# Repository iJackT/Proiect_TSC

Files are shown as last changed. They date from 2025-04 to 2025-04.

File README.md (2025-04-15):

OpenBook E-book Reader

Urmatorul fisier contine detalii despre implmentarea proiectului

Descriere generala
OpenBook este un e-reader open-source construit pe baza unui controller ESP32-C6. Acesta se foloseste de un ecran de 7.5" dar nu numai.

Diagrama Bloc:



Componente importante:

Microcontroller – ESP32-C6-WROOM-1
CPU: RISC-V pe 32 de biți, frecvență de 160 MHz
Memorie: 512 KB SRAM + 8 MB flash extern (model W25Q512JVEIQ)
Conectivitate: Suportă Wi-Fi 6 (802.11ax), Bluetooth 5 Low Energy, USB 2.0 Full-Speed

Ecran E-Ink – Waveshare WSH-13187, 7.5”
Rezoluție afișaj: 800x480 pixeli, alb-negru
Comunicare: Interfață SPI cu fire dedicate CS, DC, RST, BUSY
Consum de curent: Între 15–25 mA la reîmprospătare, consum nul în stare statică

Senzor ambiental – Bosch BME688
Măsurători: Temperatură, umiditate, presiune, calitate aer (eCO2, TVOC)
Precizie: ±1 °C (temperatură), ±3% (umiditate), ±1 hPa (presiune)
Comunicare: Protocol I²C @ 400 kHz

Alimentare și gestiunea energiei
Baterie: Li-Po 3.7V, capacitate 2500 mAh
Monitorizare baterie: MAX17048 (interfață I²C)
Încărcare: MCP73831, input 5V/1A prin conector USB-C

Interfață butoane – 3x switch tactil
Tip: Panasonic EVQ-Q2A03W
Legătură: GPIO cu debounce hardware (filtru RC)
Utilizare: Navigare în meniu, derulare pagini, confirmare acțiuni

Conector USB-C
Funcții: Încărcare baterie și transfer de date prin USB 2.0
Protecții: ESD și rezistențe de terminare corect configurate
Capabilități adiționale: Suport actualizări firmware prin USB și OTA prin Wi-Fi

Conector rapid I²C – Qwiic / STEMMA QT
Pini: VCC, GND, SDA, SCL
Rol: Permite conectarea ușoară a modulelor și senzorilor compatibili I²C

Slot MicroSD – Attend 112A-TAAR-R03
Scop: Permite stocarea externă de fișiere (cărți, jurnale, firmware)
Interfață: Conectare prin SPI

Ceas de timp real (RTC) – DS3231
Precizie: ±2 ppm
Interfață: I²C
Backup: Alimentare de rezervă prin supercapacitor

Pini folositi

| Pin ESP32-C6 | Componentă / Semnal | De ce? |
|---|---|---|
| GPIO1 | I²C SDA (BME688, MAX17048, DS3231, Qwiic) | Linie partajată I²C – economisește pini și permite extinderea facilă |
| GPIO2 | I²C SCL (BME688, MAX17048, DS3231, Qwiic) | Clock I²C pentru toți senzorii și extensii Qwiic |
| GPIO5 | SPI MISO (E-Paper, Flash extern) | Linie comună de intrare date în SPI |
| GPIO6 | SPI MOSI (E-Paper, Flash extern) | Linie de ieșire date către e-paper și flash |
| GPIO7 | SPI CLK | Semnal de clock pentru magistrala SPI |
| GPIO8 | E-Paper CS | Selectează afișajul pe magistrala SPI |
| GPIO9 | E-Paper DC (Data/Command) | Comută între comandă și date către e-paper |
| GPIO10 | E-Paper RST | Reset hardware e-paper |
| GPIO11 | E-Paper BUSY | Pin de stare (ocupat/liber) de la display |
| GPIO12 | Button #1 | Intrare digitală pentru navigare pagină înainte |
| GPIO13 | Button #2 | Intrare digitală pentru navigare pagină înapoi |
| GPIO14 | Button #3 | Intrare digitală pentru selectare/opțiune |
| GPIO15 | MAX17048 ALERT (opțional) | Pin de alertă nivel scăzut baterie |
| GPIO16 | USB D+ (intern la USB PHY) | Linie USB 2.0 (fixă pe ESP32-C6) |
| GPIO17 | USB D- (intern la USB PHY) | Linie USB 2.0 (fixă pe ESP32-C6) |
| GPIO18 | LED Status (opțional) | Indicator pentru activitate Wi-Fi, charging, notificări |
| GPIO19 | SD Card CS | Selectare chip pentru card microSD (SPI) |
| GPIO20 | SD Card MISO | Citire date de pe card microSD |
| GPIO21 | SD Card MOSI | Scriere date pe card microSD |
| GPIO4 | SD Card CLK | Semnal de clock pentru card microSD (SPI) |

Comunicatii si Interfete

| Tip | Componente |
|---|---|
| **SPI** | E-Paper, Flash extern, SD Card (în mod SPI) |
| **I²C** | BME688, MAX17048, DS3231, Qwiic/Stemma |
| **USB** | Încărcare și transfer date prin USB-C |
| **GPIO**  | Butoane, semnale control afișaj, charging enable |

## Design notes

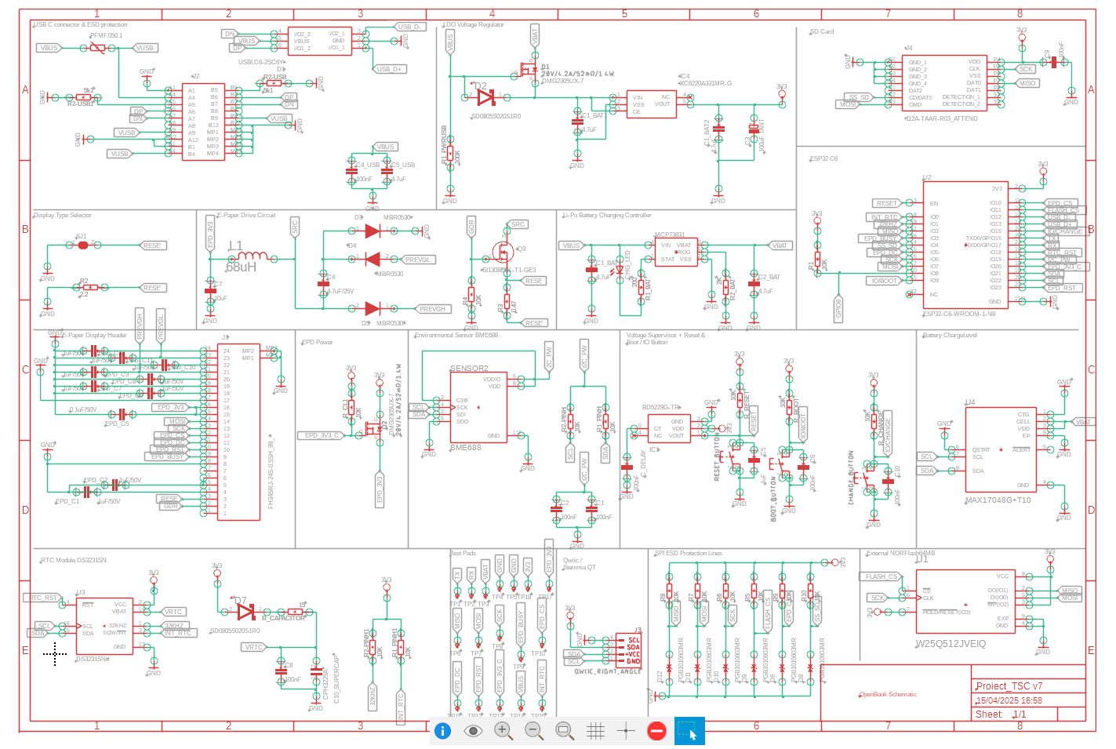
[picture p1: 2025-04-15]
Images/Screenshot 2025-04-15 170035.png

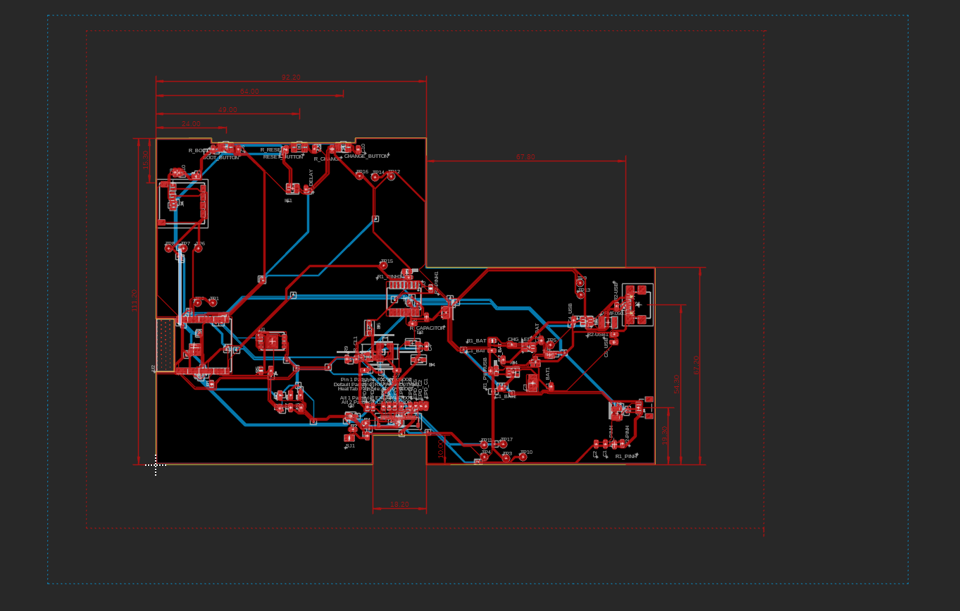
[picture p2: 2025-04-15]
Images/Screenshot 2025-04-15 170009.png

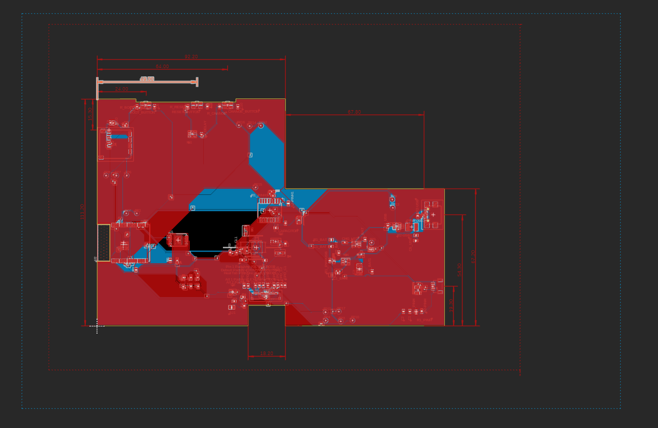
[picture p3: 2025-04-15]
Images/image.png

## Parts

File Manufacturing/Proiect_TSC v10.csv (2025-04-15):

Qty | Value | Device | Package | Parts | Description | ARROW_PART_NUMBER | ARROW_PRICE-STOCK | AVAILABILITY | CENTROID_NOT_SPECIFIED | CHECK_PRICES | COPYRIGHT | DATASHEET | DESCRIPTION | DIGIKEY_DESCRIPTION | DIGIKEY_PART_NUMBER | HEIGHT | LEAD_FREE | MANUFACTURER_NAME | MANUFACTURER_PART_NUMBER | MF | MFR_NAME | MOUSER_PART_NUMBER | MOUSER_PRICE-STOCK | MOUSER_TESTING_PART_NUMBER | MOUSER_TESTING_PRICE-STOCK | MP | MPN | PACKAGE | POPULARITY | PREFIX | PRICE | PROD_ID | PURCHASE-URL | ROHS | SNAPEDA_LINK | SPICEMODEL | SPICEPREFIX | TEMPERATURE_RANGE_HIGH | TEMPERATURE_RANGE_LOW | TP_SIGNAL_NAME | VALUE
1 |  | ADAFRUIT_LEDCHIP-LED0603 | ADAFRUIT_CHIP-LED0603 | CHG_LED | LED
1 |  | SJ | SJ | SJ1 | SMD solder JUMPER |  |  |  |  |  |  |  |  |  |  |  |  |  |  |  |  |  |  |  |  |  |  |  | 3
1 | 0.1uF/50V | EAGLE-LTSPICE_CC0402 | EAGLE-LTSPICE_C0402 | EPD_C5\ | CAPACITOR, European symbol |  |  |  |  |  |  |  |  |  |  |  |  |  |  |  |  |  |  |  |  |  |  |  |  |  |  |  |  |  |  | NONE | C
1 | 0.47 | ESP32_WROVER_EAGLE-LTSPICE_RR0402 | ESP32_WROVER_EAGLE-LTSPICE_R0402 | R3 | RESISTOR, European symbol |  |  |  |  |  |  |  |  |  |  |  |  |  |  |  |  |  |  |  |  |  |  |  |  |  |  |  |  |  |  | NONE | R
1 | 100K | ESP32_WROVER_EAGLE-LTSPICE_RR0402 | ESP32_WROVER_EAGLE-LTSPICE_R0402 | R1_PWRUSB | RESISTOR, European symbol |  |  |  |  |  |  |  |  |  |  |  |  |  |  |  |  |  |  |  |  |  |  |  |  |  |  |  |  |  |  | NONE | R
8 | 100nF | ESP32_WROVER_EAGLE-LTSPICE_CC0402 | ESP32_WROVER_EAGLE-LTSPICE_C0402 | C1, C2, C4_USB, C6, C8, C9, C10, C_DELAY | CAPACITOR, European symbol |  |  |  |  |  |  |  |  |  |  |  |  |  |  |  |  |  |  |  |  |  |  |  |  |  |  |  |  |  |  | NONE | C
1 | 100uF TANT | RCL_CPOL-EUCT3528 | RCL_CT3528 | C3 | POLARIZED CAPACITOR, European symbol |  |  |  |  |  |  |  |  |  |  |  |  |  |  |  |  |  |  |  |  |  |  |  | 0 |  |  |  |  |  |  |  | C
16 | 10K | ESP32_WROVER_EAGLE-LTSPICE_RR0402 | ESP32_WROVER_EAGLE-LTSPICE_R0402 | R1, R1_PINH, R1_PINH1, R2-PINH, R2-PINH1, R4, R5, R6, R7, R8, R9, R10, R_BOOT, R_CHANGE, R_CL1, R_RESET | RESISTOR, European symbol |  |  |  |  |  |  |  |  |  |  |  |  |  |  |  |  |  |  |  |  |  |  |  |  |  |  |  |  |  |  | NONE | R
1 | 10uF | ESP32_WROVER_EAGLE-LTSPICE_CC0402 | ESP32_WROVER_EAGLE-LTSPICE_C0402 | C7 | CAPACITOR, European symbol |  |  |  |  |  |  |  |  |  |  |  |  |  |  |  |  |  |  |  |  |  |  |  |  |  |  |  |  |  |  | NONE | C
1 | 112A-TAAR-R03_ATTEND | 112A-TAAR-R03_ATTEND | 112ATAARR03ATTEND | J4 | Micro SD Card Socket, Push-Push Type, Top Mount, SMT, H=1.83mm, 10u |  |  |  |  |  |  |  | Micro SD Card Socket | Push-Push Type | Top Mount | SMT | H=1.83mm | 10u |  |  | 1.9mm |  | ATTEND | 112A-TAAR-R03 ATTEND
1 | 15 | ESP32_WROVER_EAGLE-LTSPICE_RR0402 | ESP32_WROVER_EAGLE-LTSPICE_R0402 | R_CAPACITOR | RESISTOR, European symbol |  |  |  |  |  |  |  |  |  |  |  |  |  |  |  |  |  |  |  |  |  |  |  |  |  |  |  |  |  |  | NONE | R
1 | 1uF | ESP32_WROVER_EAGLE-LTSPICE_CC0402 | ESP32_WROVER_EAGLE-LTSPICE_C0402 | C5 | CAPACITOR, European symbol |  |  |  |  |  |  |  |  |  |  |  |  |  |  |  |  |  |  |  |  |  |  |  |  |  |  |  |  |  |  | NONE | C
7 | 1uF/50V | EAGLE-LTSPICE_CC0402 | EAGLE-LTSPICE_C0402 | EPD_C6, EPD_C7, EPD_C8, EPD_C9, EPD_C10, EPD_C11, EPD_C12 | CAPACITOR, European symbol |  |  |  |  |  |  |  |  |  |  |  |  |  |  |  |  |  |  |  |  |  |  |  |  |  |  |  |  |  |  | NONE | C
2 | 1uF/50V | ESP32_WROVER_EAGLE-LTSPICE_CC0402 | ESP32_WROVER_EAGLE-LTSPICE_C0402 | EPD_C1, EPD_C2 | CAPACITOR, European symbol |  |  |  |  |  |  |  |  |  |  |  |  |  |  |  |  |  |  |  |  |  |  |  |  |  |  |  |  |  |  | NONE | C
1 | 2.2 | ESP32_WROVER_EAGLE-LTSPICE_RR0402 | ESP32_WROVER_EAGLE-LTSPICE_R0402 | R2 | RESISTOR, European symbol |  |  |  |  |  |  |  |  |  |  |  |  |  |  |  |  |  |  |  |  |  |  |  |  |  |  |  |  |  |  | NONE | R
1 | 200 | ESP32_WROVER_EAGLE-LTSPICE_RR0402 | ESP32_WROVER_EAGLE-LTSPICE_R0402 | R1_BAT | RESISTOR, European symbol |  |  |  |  |  |  |  |  |  |  |  |  |  |  |  |  |  |  |  |  |  |  |  |  |  |  |  |  |  |  | NONE | R
2 | 20V/4.2A/52mO/1.4W | ESP32_WROVER_SPARKFUN-DISCRETESEMI_MOSFET_PCH-DMG2305UX-7 | ESP32_WROVER_SPARKFUN-DISCRETESEMI_SOT23-3 | Q1, Q2 | P-channel MOSFETs |  |  |  |  |  |  |  |  |  |  |  |  |  |  |  |  |  |  |  |  |  |  |  |  |  |  | TRAN-14388 |  |  |  |  |  |  |  |  | 20V/4.2A/52mO/1.4W
1 | 2K | ESP32_WROVER_EAGLE-LTSPICE_RR0402 | ESP32_WROVER_EAGLE-LTSPICE_R0402 | R2_BAT | RESISTOR, European symbol |  |  |  |  |  |  |  |  |  |  |  |  |  |  |  |  |  |  |  |  |  |  |  |  |  |  |  |  |  |  | NONE | R
5 | 4.7uF | ESP32_WROVER_EAGLE-LTSPICE_CC0402 | ESP32_WROVER_EAGLE-LTSPICE_C0402 | C1_BAT, C1_BAT1, C1_BAT2, C2_BAT, C5_USB | CAPACITOR, European symbol |  |  |  |  |  |  |  |  |  |  |  |  |  |  |  |  |  |  |  |  |  |  |  |  |  |  |  |  |  |  | NONE | C
1 | 4.7uF/25V | ESP32_WROVER_EAGLE-LTSPICE_CC0402 | ESP32_WROVER_EAGLE-LTSPICE_C0402 | C4 | CAPACITOR, European symbol |  |  |  |  |  |  |  |  |  |  |  |  |  |  |  |  |  |  |  |  |  |  |  |  |  |  |  |  |  |  | NONE | C
2 | 5k1 | ESP32_WROVER_EAGLE-LTSPICE_RR0402 | ESP32_WROVER_EAGLE-LTSPICE_R0402 | R2-USB, R2-USB1 | RESISTOR, European symbol |  |  |  |  |  |  |  |  |  |  |  |  |  |  |  |  |  |  |  |  |  |  |  |  |  |  |  |  |  |  | NONE | R
1 | 68uH | 744043680IND_4828-WE-TPC_WRE | IND_4828-WE-TPC_WRE | L1 |  |  |  |  |  |  | Copyright (C) 2024 Ultra Librarian. All rights reserved. |  |  |  |  |  |  |  | 744043680 |  | Wurth Electronics
1 | BD5229G-TR | BD5229G-TR | SOT95P280X125-5N | IC1 | Voltage Detector with Adjustable Delay Time: CMOS processes are utilized to develop high precision, low current consumption CMOS reset ICs that allow arbitrary setting of the delay time. The extensive lineup includes both Nch Open Drain and CMOS output types in a wide range of detection voltages (from 2.3V to 6.0V, in 0.1V steps), enabling selection of the ideal solution based on customer requirements. In addition, the entire series is of course both lead-free and RoHS-compliant. |  |  |  |  |  |  |  | Voltage Detector with Adjustable Delay Time: CMOS processes are utilized to develop high precision | low current consumption CMOS reset ICs that allow arbitrary setting of the delay time. The extensive lineup includes both Nch Open Drain and CMOS output types in a wide range of detection voltages (from 2.3V to 6.0V | in 0.1V steps) | enabling selection of the ideal solution based on customer requirements. In addition | the entire series is of course both lead-free and RoHS-compliant. |  |  | 1.25mm |  | ROHM Semiconductor | BD5229G-TR |  |  | 755-BD5229G-TR | https://www.mouser.co.uk/ProductDetail/ROHM-Semiconductor/BD5229G-TR?qs=4kLU8WoGk0vvnhrrYwdszw%3D%3D
1 | BME688 | ESP32_WROVER_BME680_BME680 | ESP32_WROVER_BME680_PSON80P300X300X100-8N | SENSOR2 | Integrated Environmental Unit |  |  | Unavailable |  |  |  |  | Integrated Environmental Unit |  |  |  |  |  |  | Bosch Sensortec |  |  |  |  |  | BME680 |  | LGA-8 Bosch Tools |  |  | None
3 | BUTTON_CUSYOMV1 | BUTTON_CUSYOMV1 | MYBUTTON | BOOT_BUTTON, CHANGE_BUTTON, RESET_BUTTON
1 | CPH3225A | CPH3225A | CAPCP3225X100N | C10_SUPERCAP | Cap 0.011F 3.3V 1210 Flat Check availability |  |  | Not in stock |  | https://www.snapeda.com/parts/CPH3225A/Seiko+Instruments/view-part/?ref=eda |  |  | 11 mF (EDLC) Supercapacitor 3.3 V 1210 (3225 Metric) - - |  |  |  |  |  |  | Seiko Instruments |  |  |  |  |  | CPH3225A |  | 1210 Seiko |  |  | None |  | https://www.snapeda.com/api/url_track_click_mouser/?unipart_id=562593&manufacturer=Seiko Instruments&part_name=CPH3225A&search_term=None |  | https://www.snapeda.com/parts/CPH3225A/Seiko+Instruments/view-part/?ref=snap
1 | DS3231SN# | DS3231SN# | SOIC127P1032X265-16N | U3 | Real Time Clock Serial 16-Pin SOIC W T/R Check availability |  |  | In Stock |  | https://www.snapeda.com/parts/DS3231SN%23/Analog+Devices/view-part/?ref=eda |  |  | Extremely Accurate I²C-Integrated RTC/TCXO/Crystal |  |  |  |  |  |  | Analog Devices |  |  |  |  |  | DS3231SN# |  | SOIC-16 Maxim |  |  | None |  | https://www.snapeda.com/api/url_track_click_mouser/?unipart_id=99048&manufacturer=Analog Devices&part_name=DS3231SN#&search_term=None |  | https://www.snapeda.com/parts/DS3231SN%23/Analog+Devices/view-part/?ref=snap
1 | ESP32-C6-WROOM-1-N8 | ESP32-C6-WROOM-1-N8 | XCVR_ESP32-C6-WROOM-1-N8 | U2 | Check availability |  |  | In Stock |  | https://www.snapeda.com/parts/ESP32-C6-WROOM-1-N8/Espressif+Systems/view-part/?ref=eda |  |  | Multiprotocol Modules ESP32-C6 module | Wi-Fi 6 in 2.4 GHz band | Bluetooth 5 | Zigbee 3.0 and Thread. ESP34-WROOM Compatible - ENGINEERING SAMPLE |  |  |  |  |  |  | Espressif Systems |  |  |  |  |  | ESP32-C6-WROOM-1-N8 |  | None |  |  | None |  |  |  | https://www.snapeda.com/parts/ESP32-C6-WROOM-1-N8/Espressif+Systems/view-part/?ref=snap
1 | ESP32C6_VARISTORCN1812 | ESP32C6_VARISTORCN1812 | ESP32C6_VARISTOR_CT/CN1812 | PFMF.050.1 | VARISTOR |  |  |  |  |  |  |  |  |  |  |  |  |  |  |  |  |  |  |  |  |  |  |  | 0
2 | ESP32_WROVER_AVX---SD0805S020S1R0_AVX_SD0805S020S1R0_0_0AVX_SD0805S020S1R0_0_0 | ESP32_WROVER_AVX---SD0805S020S1R0_AVX_SD0805S020S1R0_0_0AVX_SD0805S020S1R0_0_0 | ESP32_WROVER_AVX---SD0805S020S1R0_AVX_SD0805S020S1R0_0 | D2, D7 | Schottky Barrier Rectifier Diode |  |  |  | No |  |  | http://datasheets.avx.com/schottky.pdf |  | DIODE SCHOTTKY 20V 1A 0805 | 478-7800-1-ND |  | yes |  |  | AVX |  | 581-SD0805S020S1R0 |  |  |  |  |  | 0805 (2012 metric) |  | D |  |  |  | yes |  |  |  | +125°C | -55°C
1 | ESP32_WROVER_SPARKFUN-IC-POWER_MCP73831 | ESP32_WROVER_SPARKFUN-IC-POWER_MCP73831 | ESP32_WROVER_SPARKFUN-IC-POWER_SOT23-5 | MCP73831 | MCP73831T Li-Ion, Li-Pol Controller |  |  |  |  |  |  |  |  |  |  |  |  |  |  |  |  |  |  |  |  |  |  |  |  |  |  | IC-09995
1 | FH34SRJ-24S-0.5SH_99_ | FH34SRJ-24S-0.5SH_99_ | FH34SRJ24S05SH99 | J1 | (0.50mm) Surface Mount, Right Angle |  |  |  |  |  |  |  | 24 Position FFC | FPC Connector Contacts | (0.50mm) Surface Mount | Right Angle |  |  | 1.1mm |  | Hirose | FH34SRJ-24S-0.5SH(99) |  |  | 798-FH34SRJ24S05SH99 | https://www.mouser.co.uk/ProductDetail/Hirose-Connector/FH34SRJ-24S-0.5SH99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
1 | MAX17048G+T10 | MAX17048G+T10 | SON50P200X200X80-9N | U4 | Check availability |  |  | In Stock |  | https://www.snapeda.com/parts/MAX17048G+T10/Analog+Devices/view-part/?ref=eda |  |  | 3µA 1-Cell/2-Cell Fuel Gauge with ModelGauge |  |  |  |  |  |  | Analog Devices |  |  |  |  |  | MAX17048G+T10 |  | TDFN-8 Maxim |  |  | None |  | https://www.snapeda.com/api/url_track_click_mouser/?unipart_id=329239&manufacturer=Analog Devices&part_name=MAX17048G+T10&search_term=None |  | https://www.snapeda.com/parts/MAX17048G+T10/Analog+Devices/view-part/?ref=snap
3 | MBR0530 | MBR0530 | SOD3716X135N | D3, D4, D5 | ON SEMICONDUCTOR - MBR0530 - DIODE, SCHOTTKY, 0.5A, 30V, SOD-123 |  |  | In Stock |  | https://www.snapeda.com/parts/MBR0530/Onsemi/view-part/?ref=eda |  |  | Diode Schottky 30 V 500mA Surface Mount SOD-123 |  |  |  |  |  |  | ON Semiconductor |  |  |  |  |  | MBR0530 |  | SOD-123-2 ON Semiconductor |  |  | None |  | https://www.snapeda.com/api/url_track_click_mouser/?unipart_id=179458&manufacturer=ON Semiconductor&part_name=MBR0530&search_term=None |  | https://www.snapeda.com/parts/MBR0530/Onsemi/view-part/?ref=snap
6 | PGB1010603MR | PGB1010603MR | DIOC1608X36N | D6, D8, D9, D10, D11, D12 | Check availability |  |  | In Stock |  | https://www.snapeda.com/parts/PGB1010603MR/Littelfuse/view-part/?ref=eda |  |  | 150V (Typ) Clamp - Ipp Tvs Diode Surface Mount 0603 (1608 Metric) |  |  |  |  |  |  | Littelfuse Inc. |  |  |  |  |  | PGB1010603MR |  | 0603 Littelfuse Inc. |  |  | None |  | https://www.snapeda.com/api/url_track_click_mouser/?unipart_id=5659453&manufacturer=Littelfuse Inc.&part_name=PGB1010603MR&search_term=None |  | https://www.snapeda.com/parts/PGB1010603MR/Littelfuse/view-part/?ref=snap
1 | QWIIC_RIGHT_ANGLE | QWIIC_CONNECTORJS-1MM | JST04_1MM_RA | J3 | SparkFun I2C Standard Qwiic Connector |  |  |  |  |  |  |  |  |  |  |  |  |  |  |  |  |  |  |  |  |  |  |  |  |  |  | CONN-13694 |  |  |  |  |  |  |  |  | QWIIC_RIGHT_ANGLE
1 | SAMACSYS_PARTS_USB4110-GF-A | SAMACSYS_PARTS_USB4110-GF-A | SAMACSYS_PARTS_USB4110GFA | J2 | CONN USB 2.0 TYPE-C R/A SMT |  |  |  |  |  |  |  | CONN USB 2.0 TYPE-C R/A SMT |  |  | 3.26mm |  | GCT (GLOBAL CONNECTOR TECHNOLOGY) | USB4110-GF-A |  |  | 640-USB4110-GF-A | https://www.mouser.co.uk/ProductDetail/GCT/USB4110-GF-A?qs=KUoIvG%2F9IlYiZvIXQjyJeA%3D%3D
1 | SI1308EDL-T1-GE3 | SI1308EDL-T1-GE3 | SOT65P210X110-3N | Q3 | MOSFET N-Ch 30V 1.5A TrenchFET SC70 Vishay Si1308EDL-T1-GE3 N-channel MOSFET Transistor, 1.5 A, 30 V, 3-Pin SC-70 |  |  | In Stock |  | https://www.snapeda.com/parts/SI1308EDL-T1-GE3/Vishay+Siliconix/view-part/?ref=eda |  |  | Si1308EDL-T1-GE3 N-channel MOSFET Transistor | 1.5 A | 30 V | 3-Pin SC-70 | Siliconix / Vishay SI1308EDL-T1-GE3 |  |  |  |  |  |  | Vishay Siliconix |  |  |  |  |  | SI1308EDL-T1-GE3 |  | SOT-323 Vishay Semiconductor |  |  | None |  | https://www.snapeda.com/api/url_track_click_mouser/?unipart_id=274603&manufacturer=Vishay Siliconix&part_name=SI1308EDL-T1-GE3&search_term=None |  | https://www.snapeda.com/parts/SI1308EDL-T1-GE3/Vishay+Siliconix/view-part/?ref=snap
17 | TPTP20R | TPTP20R | TP20R | TP1, TP2, TP3, TP4, TP5, TP6, TP7, TP8, TP9, TP10, TP11, TP12, TP13, TP14, TP15, TP16, TP17 | Test pad |  |  |  |  |  |  |  |  |  |  |  |  |  |  |  |  |  |  |  |  |  |  |  | 2
1 | USBLC6-2SC6Y | USBLC6-2SC6Y | SOT95P280X145-6N | D1 | Low Cap. ESD Protection Auto SOT-23-6 STMicroelectronics USBLC6-2SC6Y, Dual Uni-Directional TVS Diode Array, 6-Pin SOT-23 |  |  | In Stock |  | https://www.snapeda.com/parts/USBLC6-2SC6Y/STMicroelectronics/view-part/?ref=eda |  |  | 17V Clamp 5A (8/20µs) Ipp Tvs Diode Surface Mount SOT-23-6 |  |  |  |  |  |  | STMicroelectronics |  |  |  |  |  | USBLC6-2SC6Y |  | SOT-23-6 STMicroelectronics |  |  | None |  |  |  | https://www.snapeda.com/parts/USBLC6-2SC6Y/STMicroelectronics/view-part/?ref=snap
1 | W25Q512JVEIQ | W25Q512JVEIQ | SON127P600X800X80-9N | U1 | Check availability |  |  | In Stock |  | https://www.snapeda.com/parts/W25Q512JVEIQ/Winbond+Electronics/view-part/?ref=eda |  |  | FLASH - NOR Memory IC 512Mb (64M x 8) SPI - Quad I/O 133 MHz 8-WSON (8x6) |  |  |  |  |  |  | Winbond Electronics |  |  |  |  |  | W25Q512JVEIQ |  | Package |  |  | None |  |  |  | https://www.snapeda.com/parts/W25Q512JVEIQ/Winbond+Electronics/view-part/?ref=snap
1 | XC6220A331MR-G | XC6220A331MR-G | SOT95P280X120-5N | IC4 | LDO Voltage Regulators |  |  |  |  |  |  |  | LDO Voltage Regulators |  |  | 1.2mm |  | Torex | XC6220A331MR-G |  |  | 865-XC6220A331MR-G | https://www.mouser.co.uk/ProductDetail/Torex-Semiconductor/XC6220A331MR-G?qs=AsjdqWjXhJ8ZSWznL1J0gg%3D%3D

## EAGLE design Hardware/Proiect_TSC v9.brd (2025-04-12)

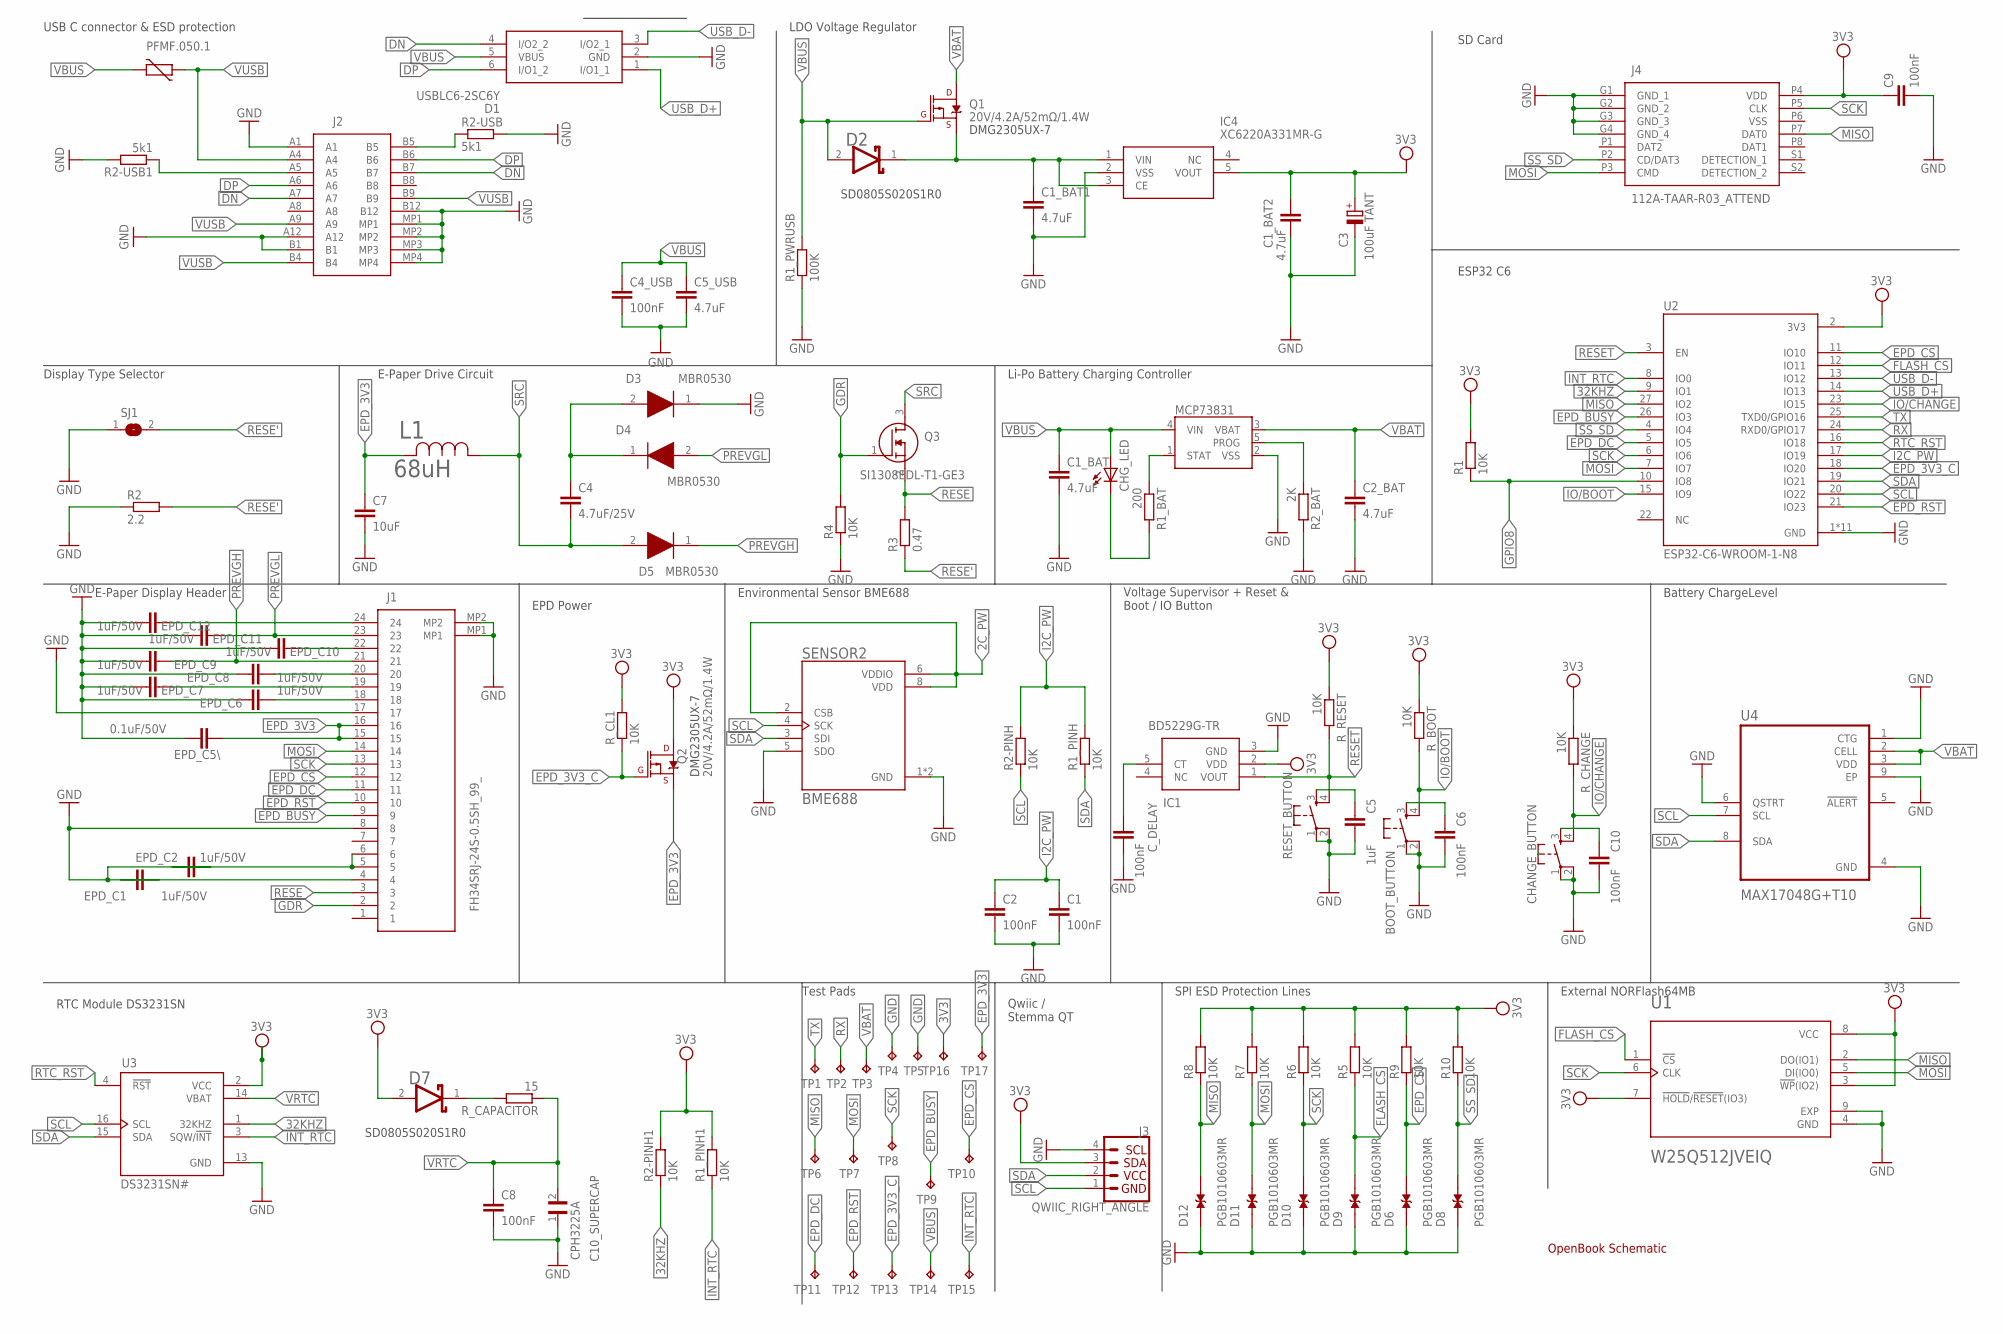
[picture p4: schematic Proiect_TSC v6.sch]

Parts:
BOOT_BUTTON: BUTTON_CUSYOMV1; MYBUTTON
C1, C2, C4_USB, C6, C8, C9, C10: 100nF; ESP32_WROVER_EAGLE-LTSPICE_C0402
C1_BAT, C1_BAT1, C1_BAT2, C2_BAT, C5_USB: 4.7uF; ESP32_WROVER_EAGLE-LTSPICE_C0402
C3: 100uF TANT; RCL_CT3528
C4: 4.7uF/25V; ESP32_WROVER_EAGLE-LTSPICE_C0402
C5: 1uF; ESP32_WROVER_EAGLE-LTSPICE_C0402
C7: 10uF; ESP32_WROVER_EAGLE-LTSPICE_C0402
C10_SUPERCAP: CPH3225A; CAPCP3225X100N
CHANGE_BUTTON: BUTTON_CUSYOMV1; MYBUTTON
CHG_LED: ADAFRUIT_LEDCHIP-LED0603; ADAFRUIT_CHIP-LED0603
C_DELAY: 100nF; ESP32_WROVER_EAGLE-LTSPICE_C0402
D1: USBLC6-2SC6Y; SOT95P280X145-6N
D2, D7: ESP32_WROVER_AVX---SD0805S020S1R0_AVX_SD0805S020S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; ESP32_WROVER_AVX---SD0805S020S1R0_AVX_SD0805S020S1R0_0
D3, D4, D5: MBR0530; SOD3716X135N
D6, D8, D9, D10, D11, D12: PGB1010603MR; DIOC1608X36N
EPD_C1, EPD_C2: 1uF/50V; ESP32_WROVER_EAGLE-LTSPICE_C0402
EPD_C5\: 0.1uF/50V; EAGLE-LTSPICE_C0402
EPD_C6, EPD_C7, EPD_C8, EPD_C9, EPD_C10, EPD_C11, EPD_C12: 1uF/50V; EAGLE-LTSPICE_C0402
IC1: BD5229G-TR; SOT95P280X125-5N
IC4: XC6220A331MR-G; SOT95P280X120-5N
J1: FH34SRJ-24S-0.5SH_99_; FH34SRJ24S05SH99
J2: SAMACSYS_PARTS_USB4110-GF-A; SAMACSYS_PARTS_USB4110GFA
J3: QWIIC_RIGHT_ANGLE; JST04_1MM_RA
J4: 112A-TAAR-R03_ATTEND; 112ATAARR03ATTEND
L1: 68uH; IND_4828-WE-TPC_WRE
MCP73831: ESP32_WROVER_SPARKFUN-IC-POWER_MCP73831; ESP32_WROVER_SPARKFUN-IC-POWER_SOT23-5
PFMF.050.1: ESP32C6_VARISTORCN1812; ESP32C6_VARISTOR_CT/CN1812
Q1, Q2: 20V/4.2A/52mΩ/1.4W; ESP32_WROVER_SPARKFUN-DISCRETESEMI_SOT23-3
Q3: SI1308EDL-T1-GE3; SOT65P210X110-3N
R1, R1_PINH, R1_PINH1, R2-PINH, R2-PINH1, R4, R5, R6, R7, R8, R9, R10: 10K; ESP32_WROVER_EAGLE-LTSPICE_R0402
R1_BAT: 200; ESP32_WROVER_EAGLE-LTSPICE_R0402
R1_PWRUSB: 100K; ESP32_WROVER_EAGLE-LTSPICE_R0402
R2: 2.2; ESP32_WROVER_EAGLE-LTSPICE_R0402
R2-USB, R2-USB1: 5k1; ESP32_WROVER_EAGLE-LTSPICE_R0402
R2_BAT: 2K; ESP32_WROVER_EAGLE-LTSPICE_R0402
R3: 0.47; ESP32_WROVER_EAGLE-LTSPICE_R0402
RESET_BUTTON: BUTTON_CUSYOMV1; MYBUTTON
R_BOOT: 10K; ESP32_WROVER_EAGLE-LTSPICE_R0402
R_CAPACITOR: 15; ESP32_WROVER_EAGLE-LTSPICE_R0402
R_CHANGE: 10K; ESP32_WROVER_EAGLE-LTSPICE_R0402
R_CL1: 10K; ESP32_WROVER_EAGLE-LTSPICE_R0402
R_RESET: 10K; ESP32_WROVER_EAGLE-LTSPICE_R0402
SENSOR2: BME688; ESP32_WROVER_BME680_PSON80P300X300X100-8N
SJ1: SJ
TP1, TP2, TP3, TP4, TP5, TP6, TP7, TP8, TP9, TP10, TP11, TP12, TP13, TP14, TP15, TP16, TP17: TPTP20R; TP20R
U1: W25Q512JVEIQ; SON127P600X800X80-9N
U2: ESP32-C6-WROOM-1-N8; XCVR_ESP32-C6-WROOM-1-N8
U3: DS3231SN#; SOIC127P1032X265-16N
U4: MAX17048G+T10; SON50P200X200X80-9N

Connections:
2C_PW: SENSOR2.2 (CSB), SENSOR2.6 (VDDIO), SENSOR2.8 (VDD)
3V3: C1_BAT2.1, C3.+, C9.1, D7.2 (ANODE), IC1.2 (VDD), IC4.5 (VOUT), J3.3, J4.P4 (VDD), Q2.3 (D), R1.2, R1_PINH1.2, R2-PINH1.2, R5.2, R6.2, R7.2, R8.2, R9.2, R10.2, R_BOOT.1, R_CHANGE.1, R_CL1.2, R_RESET.1, TP16.TP, U1.3 (!WP!(IO2)), U1.7 (!HOLD!/!RESET!(IO3)), U1.8 (VCC), U2.2 (3V3), U3.2 (VCC)
32KHZ: R2-PINH1.1, U2.9 (IO1), U3.1 (32KHZ)
DN: D1.4 (I/O2_2), J2.A7, J2.B7
DP: D1.6 (I/O1_2), J2.A6, J2.B6
EPD_3V3: C7.1, EPD_C5\.1, J1.15, J1.16, L1.2, Q2.2 (S), TP17.TP
EPD_3V3_C: Q2.1 (G), R_CL1.1, TP13.TP, U2.18 (IO20)
EPD_BUSY: J1.9, TP9.TP, U2.26 (IO3)
EPD_C2: EPD_C2.2, J1.5, J1.6
EPD_CS: D6.2, J1.12, R9.1, TP10.TP, U2.11 (IO10)
EPD_DC: J1.11, TP11.TP, U2.5 (IO5)
EPD_RST: J1.10, TP12.TP, U2.21 (IO23)
FLASH_CS: D9.2, R5.1, U1.1 (!CS), U2.12 (IO11)
GDR: J1.2, Q3.1 (G), R4.2
GND: BOOT_BUTTON.2, C1.2, C1_BAT.2, C1_BAT1.2, C1_BAT2.2, C2.2, C2_BAT.2, C3.-, C4_USB.2, C5.2, C5_USB.2, C6.2, C7.2, C8.2, C9.2, C10.2, C10_SUPERCAP.1, CHANGE_BUTTON.2, C_DELAY.2, D1.2 (GND), D3.1 (K), D6.1, D8.1, D9.1, D10.1, D11.1, D12.1, EPD_C1.1, EPD_C2.1, EPD_C5\.2, EPD_C6.2, EPD_C7.2, EPD_C8.2, EPD_C9.2, EPD_C10.2, EPD_C11.2, EPD_C12.2, IC1.3 (GND), IC4.2 (VSS), J1.8, J1.17, J1.MP1, J1.MP2, J2.A1, J2.A12, J2.B1, J2.B12, J2.MP1, J2.MP2, J2.MP3, J2.MP4, J3.4, J4.G1 (GND_1), J4.G2 (GND_2), J4.G3 (GND_3), J4.G4 (GND_4), MCP73831.2 (VSS), R1_PWRUSB.1, R2.1, R2-USB.2, R2-USB1.2, R2_BAT.2, R4.1, RESET_BUTTON.1, RESET_BUTTON.2, SENSOR2.1 (GND), SENSOR2.5 (SDO), SENSOR2.7 (GND), SJ1.1, TP4.TP, TP5.TP, U1.4 (GND), U1.9 (EXP), U2.1 (GND), U2.28 (GND), U2.29_1 (GND), U2.29_2 (GND), U2.29_3 (GND), U2.29_4 (GND), U2.29_5 (GND), U2.29_6 (GND), U2.29_7 (GND), U2.29_8 (GND), U2.29_9 (GND), U3.13 (GND), U4.1 (CTG), U4.4 (GND), U4.6 (QSTRT), U4.9 (EP)
GPIO8: R1.1, U2.10 (IO8)
I2C_PW: C1.1, C2.1, R1_PINH.2, R2-PINH.2, U2.17 (IO19)
INT_RTC: R1_PINH1.1, TP15.TP, U2.8 (IO0), U3.3 (SQW/!INT)
IO/BOOT: BOOT_BUTTON.4, R_BOOT.2, U2.15 (IO9)
IO/CHANGE: CHANGE_BUTTON.4, R_CHANGE.2, U2.23 (IO15)
MISO: D12.2, J4.P7 (DAT0), R8.1, TP6.TP, U1.2 (DO(IO1)), U2.27 (IO2)
MOSI: D11.2, J1.14, J4.P3 (CMD), R7.1, TP7.TP, U1.5 (DI(IO0)), U2.7 (IO7)
unnamed: J2.A5, R2-USB1.1
unnamed: J2.B5, R2-USB.1
unnamed: C1_BAT1.1, D2.1 (CATHODE), IC4.1 (VIN), IC4.3 (CE), Q1.2 (S)
unnamed: MCP73831.5 (PROG), R2_BAT.1
unnamed: C4.1, D3.2 (A), D4.1 (K)
unnamed: C_DELAY.1, IC1.5 (CT)
unnamed: EPD_C1.2, J1.4
unnamed: MCP73831.1 (STAT), R1_BAT.1
unnamed: CHG_LED.C, R1_BAT.2
unnamed: EPD_C6.1, J1.18
unnamed: EPD_C7.1, J1.19
unnamed: EPD_C8.1, J1.20
unnamed: D7.1 (CATHODE), R_CAPACITOR.2
unnamed: EPD_C10.1, J1.22
unnamed: BOOT_BUTTON.3, C6.1
unnamed: EPD_C12.1, J1.24
unnamed: C5.1, RESET_BUTTON.3
unnamed: C10.1, CHANGE_BUTTON.3
PREVGH: D5.1 (K), EPD_C9.1, J1.21
PREVGL: D4.2 (A), EPD_C11.1, J1.23
RESE: J1.3, Q3.2 (S), R3.2
RESE': R2.2, R3.1, SJ1.2
RESET: IC1.1 (VOUT), RESET_BUTTON.4, R_RESET.2, U2.3 (EN)
RTC_RST: U2.16 (IO18), U3.4 (!RST)
RX: TP2.TP, U2.24 (RXD0/GPIO17)
SCK: D10.2, J1.13, J4.P5 (CLK), R6.1, TP8.TP, U1.6 (CLK), U2.6 (IO6)
SCL: J3.1, R2-PINH.1, SENSOR2.4 (SCK), U2.20 (IO22), U3.16 (SCL), U4.7 (SCL)
SDA: J3.2, R1_PINH.1, SENSOR2.3 (SDI), U2.19 (IO21), U3.15 (SDA), U4.8 (SDA)
SRC: C4.2, D5.2 (A), L1.1, Q3.3 (D)
SS_SD: D8.2, J4.P2 (CD/DAT3), R10.1, U2.4 (IO4)
TX: TP1.TP, U2.25 (TXD0/GPIO16)
USB_D+: D1.1 (I/O1_1), U2.14 (IO13)
USB_D-: D1.3 (I/O2_1), U2.13 (IO12)
VBAT: C2_BAT.1, MCP73831.3 (VBAT), Q1.3 (D), TP3.TP, U4.2 (CELL), U4.3 (VDD)
VBUS: C1_BAT.1, C4_USB.1, C5_USB.1, CHG_LED.A, D1.5 (VBUS), D2.2 (ANODE), MCP73831.4 (VIN), PFMF.050.1.2, Q1.1 (G), R1_PWRUSB.2, TP14.TP
VRTC: C8.1, C10_SUPERCAP.2, R_CAPACITOR.1, U3.14 (VBAT)
VUSB: J2.A4, J2.A9, J2.B4, J2.B9, PFMF.050.1.1

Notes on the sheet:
USB C connector & ESD protection
DMG2305UX-7
LDO Voltage Regulator
SD Card
Display Type Selector
E-Paper Drive Circuit
Li-Po Battery Charging Controller
ESP32 C6
EPD Power
Battery ChargeLevel
E-Paper Display Header
SD0805S020S1R0
RTC Module DS3231SN
Test Pads
Qwiic / Stemma QT
SPI ESD Protection Lines
OpenBook Schematic
External NORFlash64MB
Environmental Sensor BME688
Voltage Supervisor + Reset & Boot / IO Button

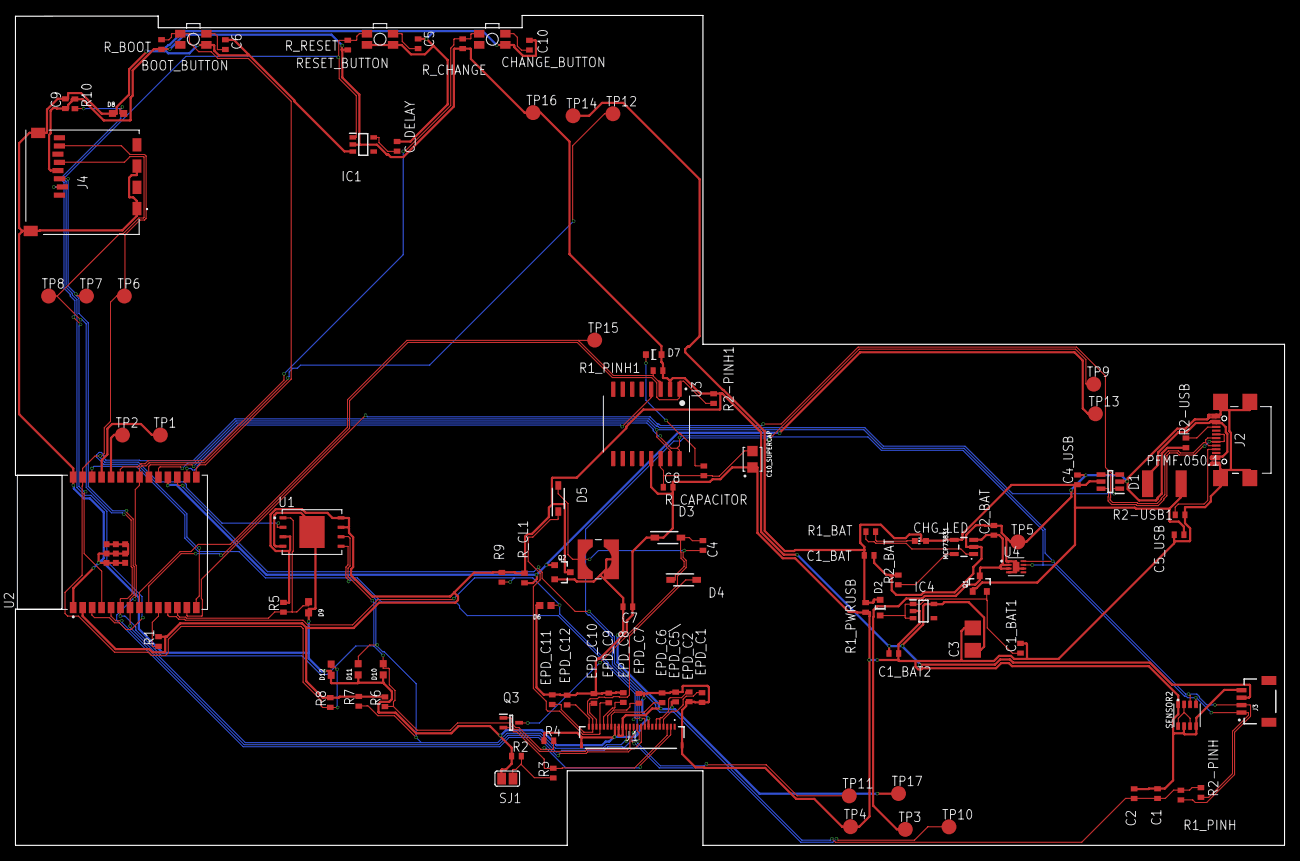
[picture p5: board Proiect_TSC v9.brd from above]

Board: 2 copper layers, 170.2 x 111.3 mm, 103 parts (0 on the bottom side), 59 nets.

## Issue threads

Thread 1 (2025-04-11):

PCB – plan GND incorect

andreiv03, 2025-04-11:
## Descriere:
GND-ul nu este realizat corect pe layer-ele de **Top** și **Bottom**. Fie lipsește complet, fie este implementat greșit.

## Probleme identificate:
- **Layer Top** – GND lipsește sau este configurat greșit.
- **Layer Bottom** – GND lipsește sau este configurat greșit.

## Task:
- Asigură-te că există GND corect realizat pe ambele straturi (top și bottom).
- Verifică dacă toate componentele care trebuie conectate la GND sunt legate corespunzător.
- Respectă structura indicată în documentația oficială (poza de pe OCW).

Closed 2025-04-12.

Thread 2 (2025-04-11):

Schematic – denumiri și tag-uri lipsă

andreiv03, 2025-04-11:
## Descriere:
Schematicul actual nu respectă standardele din documentație (vezi poza de pe OCW).

## Probleme identificate:
- **Toate chenarele** – Lipsesc denumirile în colțul din dreapta sus.
- **USB-C Connector & ESD Protection** – Lipsesc tag-uri la unele componente.
- **LDO Voltage Regulator** – O componentă nu are denumire.
- **ESP32-C6** – Lipsește un tag.
- **Environmental Sensor BME688** – Lipsesc denumiri.
- **Voltage Supervisor + Reset & Boot/IO Button** – Lipsesc denumiri.

## Task:
- Adaugă `name` și `tag` la toate componentele.
- Completează colțurile din dreapta sus ale chenarelor conform standardului din documentație.

Closed 2025-04-12.

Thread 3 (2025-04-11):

PCB – erori plasare TP, U2 și butoane

andreiv03, 2025-04-11:
## Descriere:
Există mai multe probleme legate de plasarea TP-urilor, margini ale plăcuței și componente dispuse incorect, care contravin cerințelor din documentație.

## Probleme identificate:
- **Test Points (TP)**
5 TP-uri trebuiau plasate în poziții specifice conform documentației.
Restul puteau fi poziționate flexibil, dar nu au fost plasate corespunzător.

- **Piesa U2**
Zona punctată trebuia decupată și lăsată în afara conturului plăcuței.
Conturul plăcii nu trebuia să includă acea zonă.

- **Butoane**
Trebuiau scoase parțial în afara plăcii.
Tăietura din placă a fost făcută special pentru acest lucru, dar nu a fost utilizată corect.

- **Erori nerezolvate**
Sunt multiple erori rămase în design care ar fi trebuit corectate.

## Task:
- **Replasează TP-urile** – 5 conform pozițiilor indicate, restul într-un mod optim.
- **Corectează zona U2** – decupează conform cerinței, fără extinderea conturului plăcii.
- Reașează butoanele pentru a ieși ușor în afara PCB-ului, folosind tăietura existentă.
- Revizuiește și rezolvă toate erorile semnalate în schematic și layout.

Closed 2025-04-12.

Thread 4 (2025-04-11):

Componente lipsă din enunț

andreiv03, 2025-04-11:
## Descriere:
Proiectul este incomplet și nu respectă cerințele minime. Lipsesc elemente esențiale atât din partea de documentație, cât și din designul efectiv al plăcii.

## Probleme identificate:
- **README** – Lipsește complet.
- **3D View** – Nu a fost generată/redată.
- **Componente lipsă** – carcasă, baterie, display

## Task:
- Asigură-te că proiectul este complet și documentat corespunzător.

Closed 2025-04-23.

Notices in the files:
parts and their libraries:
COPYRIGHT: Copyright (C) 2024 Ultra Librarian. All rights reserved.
